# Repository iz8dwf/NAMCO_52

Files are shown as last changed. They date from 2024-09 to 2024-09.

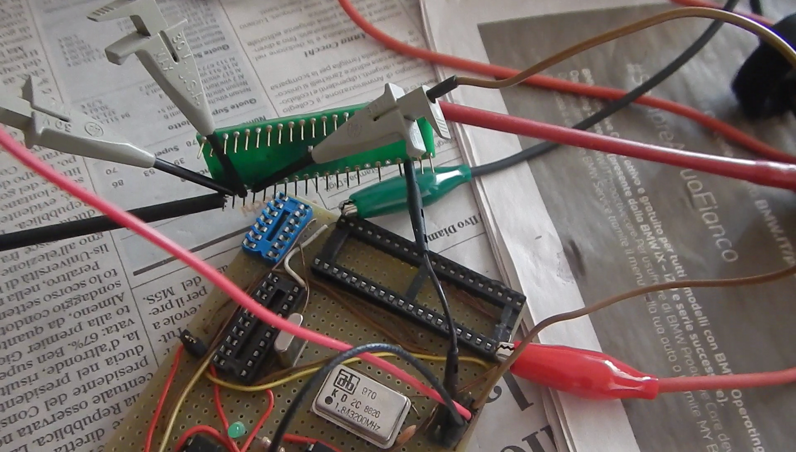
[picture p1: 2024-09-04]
images/serialprogramming.png

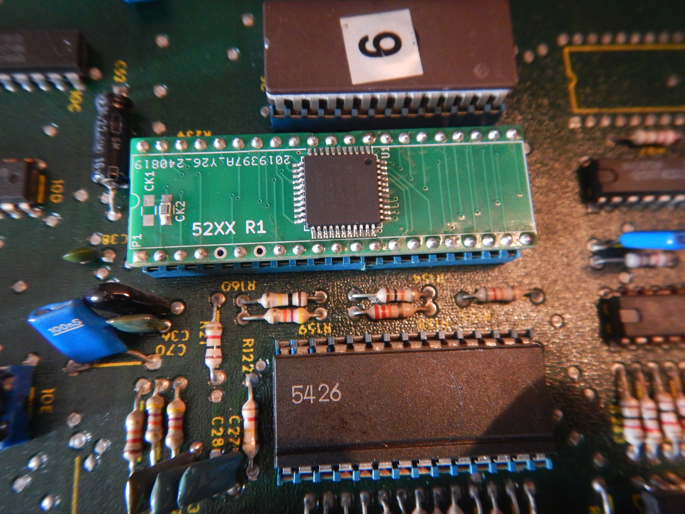
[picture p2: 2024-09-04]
images/poleposition.jpg

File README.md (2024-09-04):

# Namco_52_avr
Namco 52xx custom IC replacement

This daughterboard replaces the 52XX custom IC used for example in Pole
Position as speech generator.
It is implemented with a 44 pin ATMega8515 MCU following the reverse 
engineering information found at http://www.whiterocker.com/blog/namco-52xx.html

I've also checked both the Pole Position schematic and 52xx's ROM and the 
Bosconian schematic and its 52xx ROM and of course MAME's implementation, see the info 
subdirectory.
It seems that on Bosconian the 52xx clock arrives on PIN 1 instead of PIN 2 as on 
Pole Position, so in that case, a 0 ohms resistor or jumper must be soldered on CK1
position. ONLY solder one jumper either on CK1 OR CK2.

The MCU can be programmed by connecting the appropriate daughterboard pins 
to the needed SPI pins. I've not added any programming header for laziness/space
reasons, see the images.

WARNING: only tested on Pole Position!!!

If you want to try this replacement on another game contact me first!

USE AT YOUR OWN RISK

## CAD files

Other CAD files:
firmware/52_M8515.obj

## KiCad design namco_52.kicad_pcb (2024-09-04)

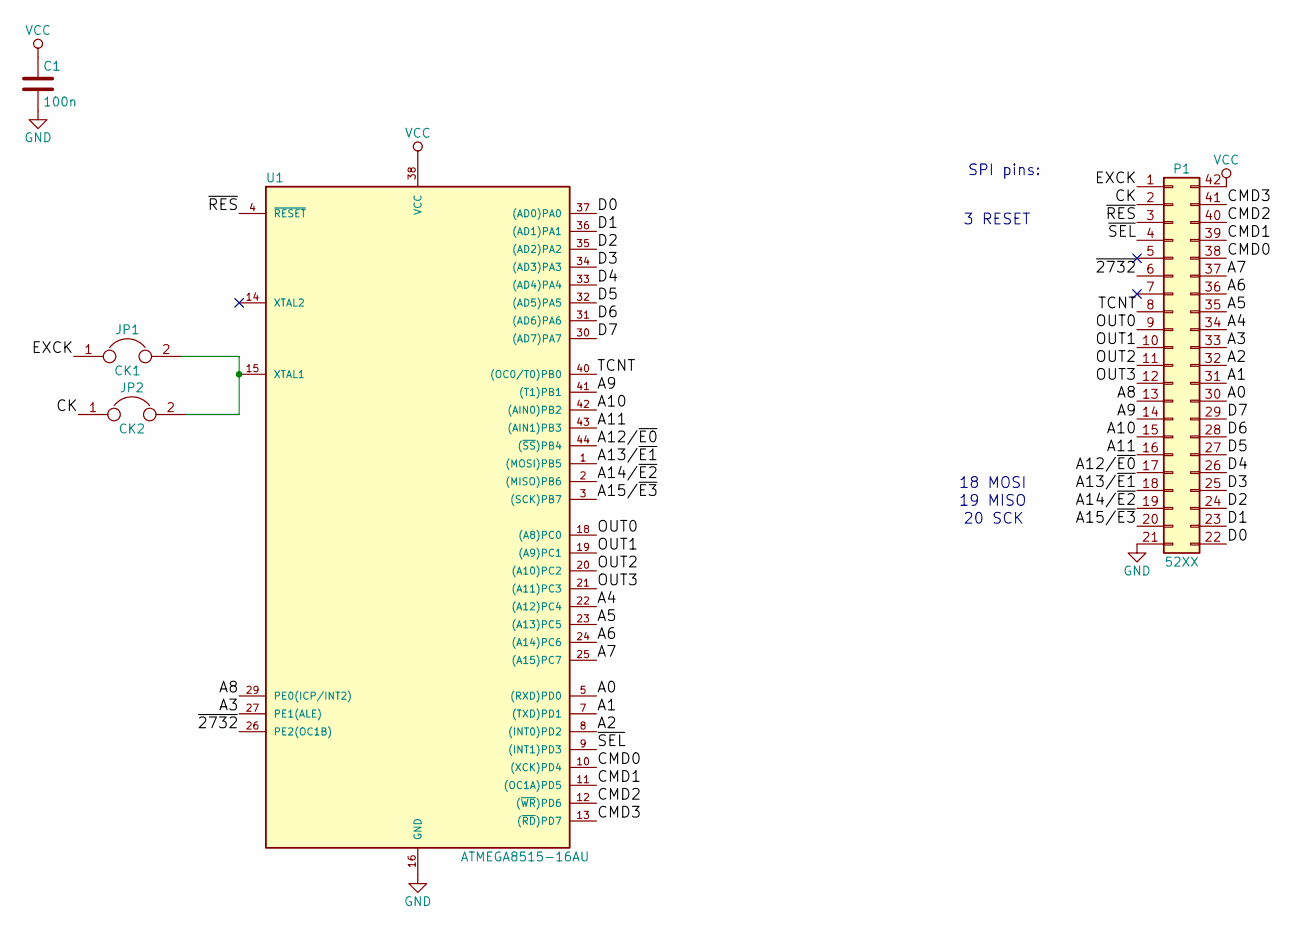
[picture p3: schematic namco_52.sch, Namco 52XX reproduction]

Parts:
C1: 100n; C_0805_HandSoldering
JP1: CK1; R_0805_HandSoldering
JP2: CK2; R_0805_HandSoldering
P1: 52XX; DIP-42_W15.24mm
U1: ATMEGA8515-16AU; TQFP-44_10x10mm_Pitch0.8mm

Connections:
/A0: P1.30, U1.5 ((RXD)PD0)
/A1: P1.31, U1.7 ((TXD)PD1)
/A2: P1.32, U1.8 ((INT0)PD2)
/A3: P1.33, U1.27 (PE1(ALE))
/A4: P1.34, U1.22 ((A12)PC4)
/A5: P1.35, U1.23 ((A13)PC5)
/A6: P1.36, U1.24 ((A14)PC6)
/A7: P1.37, U1.25 ((A15)PC7)
/A8: P1.13, U1.29 (PE0(ICP/INT2))
/A9: P1.14, U1.41 ((T1)PB1)
/A10: P1.15, U1.42 ((AIN0)PB2)
/A11: P1.16, U1.43 ((AIN1)PB3)
/A12/~E0: P1.17, U1.44 ((~SS~)PB4)
/A13/~E1: P1.18, U1.1 ((MOSI)PB5)
/A14/~E2: P1.19, U1.2 ((MISO)PB6)
/A15/~E3: P1.20, U1.3 ((SCK)PB7)
/CK: JP2.1, P1.2
/CMD0: P1.38, U1.10 ((XCK)PD4)
/CMD1: P1.39, U1.11 ((OC1A)PD5)
/CMD2: P1.40, U1.12 ((~WR~)PD6)
/CMD3: P1.41, U1.13 ((~RD~)PD7)
/D0: P1.22, U1.37 ((AD0)PA0)
/D1: P1.23, U1.36 ((AD1)PA1)
/D2: P1.24, U1.35 ((AD2)PA2)
/D3: P1.25, U1.34 ((AD3)PA3)
/D4: P1.26, U1.33 ((AD4)PA4)
/D5: P1.27, U1.32 ((AD5)PA5)
/D6: P1.28, U1.31 ((AD6)PA6)
/D7: P1.29, U1.30 ((AD7)PA7)
/EXCK: JP1.1, P1.1
/OUT0: P1.9, U1.18 ((A8)PC0)
/OUT1: P1.10, U1.19 ((A9)PC1)
/OUT2: P1.11, U1.20 ((A10)PC2)
/OUT3: P1.12, U1.21 ((A11)PC3)
/TCNT: P1.8, U1.40 ((OC0/T0)PB0)
/~2732: P1.6, U1.26 (PE2(OC1B))
/~RES: P1.3, U1.4 (~RESET)
/~SEL: P1.4, U1.9 ((INT1)PD3)
GND: C1.2, P1.21, U1.16 (GND)
unnamed: JP1.2, JP2.2, U1.15 (XTAL1)
VCC: C1.1, P1.42, U1.38 (VCC)

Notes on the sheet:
18 MOSI
SPI pins:
19 MISO
20 SCK
3 RESET

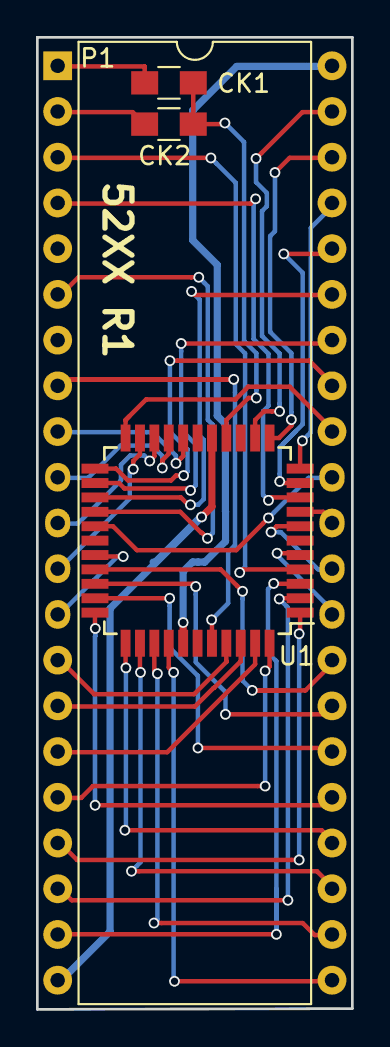
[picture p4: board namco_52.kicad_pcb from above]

Board: 2 copper layers, 17.5 x 54.0 mm, 5 parts (1 on the bottom side), 41 nets.

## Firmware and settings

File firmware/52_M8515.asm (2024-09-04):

; Namco 52XX replacement
; ATMega8515 MCU
; V 1.0
; IZ8DWF 08/2024

.device  ATmega8515

; fuses: CKSEL3..0 = 0000 (external clock)
;        CKOPT = 1, BOOTRST = 1
;        HB 11011001 0xd9
;        LB 11100000 0xe0

; Inputs:
; Port A = byte read from ROM
; Port D7..4 = sample index from CPU (read during INT1)
; PE2 = /2732 read during initialization

; PB0 special  (T0 for external counter clock)
; PD3 special  (INT1)

; Outputs:
; PB1 = A9
; PB2 = A10
; PB3 = A11
; PB4 = A12 if /2732 = 1, /E0 if 0
; PB5 = A13 if /2732 = 1, /E1 if 0
; PB6 = A14 if /2732 = 1, /E2 if 0
; PB7 = A15 if /2732 = 1, /E3 if 0

; PC7..4  = A7..4
; PD2..0  = A2..0
; PE1 = A3
; PE0 = A8

; registers map
; r0 = always 0
; r1 = /2732
; r2 = general purpose
; r3 = playing clip index
; r4 = used in address output routine
; r5 = status register save in interrupts

; r16 = general purpose always lost (DO NOT use in interrupts)
; r17 = clip index read from CPU
; r18 = general purpose (mostly used in ROM address output)
; r19 = current sample
; r20 = timer compare value/interrupt enable mask
; r21 = only used in timer interrupt routine
; r22 = only used in timer interrupt routine

; r24 = sample index

; r26 low, r27 high = X 
; r28 low, r29 high = Y
; r30 low, r31 high = Z

; ATMega8515 I/O space

.equ base = 0x0000
.equ init = 0x0011
.equ ram  = 0x0060
.equ ramend = 0x025f

.equ SREG = 0x3f
.equ SPH = 0x3e
.equ SPL = 0x3d
.equ GICR = 0x3b
.equ GIFR = 0x3a
.equ TIMSK = 0x39
.equ TIFR = 0x38
.equ SPMCR = 0x37
.equ EMCUCR = 0x36
.equ MCUCR = 0x35
.equ MCUCSR = 0x34
.equ TCCR0 = 0x33
.equ TCNT0 = 0x32
.equ OCR0 = 0x31
.equ SFIOR = 0x30
.equ TCCR1A = 0x2f
.equ TCCR1B = 0x2e
.equ TCNT1H = 0x2d
.equ TCNT1L = 0x2c
.equ OCR1AH = 0x2b
.equ OCR1AL = 0x2a
.equ OCR1BH = 0x29
.equ OCR1BL = 0x28
.equ ICR1H = 0x25
.equ ICR1L = 0x24
.equ WDTCR = 0x21
.equ UBRRH = 0x20
.equ UCSRC = 0x20
.equ EEARH = 0x1f
.equ EEARL = 0x1e
.equ EEDR = 0x1d
.equ EECR = 0x1c
.equ PORTA = 0x1b
.equ DDRA = 0x1a
.equ PINA = 0x19
.equ PORTB = 0x18
.equ DDRB = 0x17
.equ PINB = 0x16
.equ PORTC = 0x15
.equ DDRC = 0x14
.equ PINC = 0x13
.equ PORTD = 0x12
.equ DDRD = 0x11
.equ PIND = 0x10
.equ SPDR = 0x0f
.equ SPSR = 0x0e
.equ SPCR = 0x0d
.equ UDR = 0x0c
.equ UCSRA = 0x0b
.equ UCSRB = 0x0a
.equ UBRRL = 0x09
.equ ACSR = 0x08
.equ PORTE = 0x07
.equ DDRE = 0x06
.equ PINE = 0x05
.equ OSCCAL = 0x04


; ram/local constants 
; timer compare value on Pole Position should result in approx. 4 kHz sample
; reproduction rate.
.equ INTMAX	= 0x30	; internal timer compare (top) value

; timer compare value when using external clock. Assuming it's 1 cycle = 
; 1 sample. I've never seen an actual board using external clock so far
.equ EXTMAX	= 0x01	; external timer compare (top)  value

.cseg
.org base
	rjmp RESET
	rjmp DUMMYI	; external interrupt 0
	rjmp INT1	; external interrupt 1
	rjmp DUMMYI	; timer 1 capture
	rjmp DUMMYI	; timer 1 compare A
	rjmp DUMMYI	; timer 1 compare B
	rjmp DUMMYI	; timer 1 overflow 
	rjmp DUMMYI	; timer 0 overflow 
	rjmp DUMMYI	; SPI serial xfer complete 
	rjmp DUMMYI	; uart rxc
	rjmp DUMMYI	; uart udre
	rjmp DUMMYI	; uart txc
	rjmp DUMMYI	; analog comp
	rjmp DUMMYI	; external interrupt 2
	rjmp TMI	; timer 0 compare
	rjmp DUMMYI	; eeprom ready
	rjmp DUMMYI	; store program memory ready
	
.org init


INT1:
	in r17, PIND	; read sample clip index 
	in r5, SREG	; save status register
	andi r17, 0xf0  ; data is on high nibble only
	swap r17	; so put it on low nibble now
	out SREG, r5	; restore status
DUMMYI:	reti

TMI:
	in r5, SREG	; save status register
	in r21, PORTC
	andi r21, 0xf0
	mov r22, r19
	andi r22, 0x0f
	or r22, r21
	out PORTC, r22
	swap r19
	inc r24		; increment played sample index
	out SREG, r5	; restore status
	reti

RESET:	cli
	sbi ACSR, 7		; power off analog comparator
	clr r0
	clr r17			; clear sample index register
	out DDRA, r17		; port A is all inputs
	out PORTA, r17		; also disable pullups

	ldi r16, low(ramend)	; set stack pointer (low byte)
	out SPL, r16
	ldi r16, high(ramend)	; high byte now
	out SPH, r16

	ldi r16, 0xfe		
	out DDRB, r16		; PB1 to PB7 are outputs
	ldi r16, 0xff		
	out DDRC, r16		; PC0 to PC7 are outputs
	ldi r16, 0x07		
	out DDRD, r16		; PD0 to PD2  are outputs
	ldi r16, 0x03		
	out DDRE, r16		; PE0 and PE1 are outputs	
	cbi PORTE, 2		; disable pullup on PE2 input
	clr r1
	sbic PINE, 2		; check /2732 pin
	inc r1
	clr r27			; check configuration byte at ROM addr 0x0020
	ldi r26, 0x20
	rcall romrd
	in r18, PINA
	ldi r20, INTMAX		; set the timer top value
	ldi r16, 0x0a		; CTC, internal clock prescaler = 1/8
	cpi r18, 0xf0		; internal timer = 0xf0, external = 0xff
	breq timinit 
	ldi r20, EXTMAX
	ldi r16, 0x0f		; CTC, external clock rising edge
timinit:
	out OCR0, r20
	out TCCR0, r16
	ldi r20, 0x01		; timer interrupt on compare match
	
	in r16, MCUCR		; setup INT1 as falling edge
	ori r16, 0x08
	out MCUCR, r16
	in r16, GICR
	ori r16, 0x80		; enable INT1
	out GICR, r16
	sei			; enable interrupts

main:
	tst r17 		; waits for a clip index
	breq main		; (no clip playing if looping here)

clip:	rcall getadd		; get start/stop addresses of the clip to play
	clr r24			; clear sample index
	rcall rsamp		; get first sample pair in r19
	mov r3, r17	
	out TCNT0, r0		; timer is running, so reset its value
	out TIFR, r20		; then clear the interrupt flag 
	out TIMSK, r20		; then enable timer 0 OC interrupt
waitpl:	cpi r24, 0x02		; wait for current samples to be played
	brlo waitpl

	cp r29, r31		; check if we are at the end of the samples
	brne nextrd
	cp r28, r30
	brne nextrd
	out TIMSK, r0		; end: disable all timer 0/1 interrupts
	clr r17
	rjmp main

nextrd:	cp r3, r17		; see if we got a higher clip to play
	brlo clip		; yes, start the new one
	adiw r28, 0x01		; otherwise increment sample address
	rcall rsamp		; read a new sample pair in r19
	clr r24	
	rjmp waitpl

; subroutines


rsamp:	movw r26, r28
	rcall romrd
	in r19, PINA
	ret

getadd:				; gets start (Y) and stop (Z) addresses
				; of the clip index in r17
	clr r26
	clr r27
	add r26, r17		; low clip end address at 0x0000 + clip
	rcall romrd		
	in r30, PINA
	dec r26			; low clip start address at 0x0000 + clip - 1
	rcall romrd
	in r28, PINA		
	adiw r26, 0x10		; high clip start address at 0x0010 + clip - 1
	rcall romrd
	in r29, PINA
	inc r26			; high clip end address at 0x0010 + clip
	rcall romrd		
	in r31, PINA
	ret
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
